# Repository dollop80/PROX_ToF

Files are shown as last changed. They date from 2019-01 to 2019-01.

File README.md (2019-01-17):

# Copter Obstacle Avoidance for Ardupilot - PROX_ToF
The obstacle avoidance module is based on ToF (Time of Flight) distance sensors VL53L1. The module is rather small and lightweight so it can fit even 140mm frame



You can read about obstacle avoidance in Ardupilot [here](http://ardupilot.org/dev/docs/code-overview-object-avoidance.html)

## What do you need:
- PROX_ToF PCB and parts
- Ardupilot compatible flight controller (Pixhawk, Omnibus, Pixracer, etc)
- Optical flow sensor (FlowDeck or Cheerson CX-OF)
- Any AVR ISP programmer to flash bootloader
- Your favorite quad, tri, hexa, octo :)

## Preparing Hardware:
- Assemble your [PROX_ToF module](https://github.com/dollop80/PROX_ToF/tree/master/HW) and flash a bootloader using AVR ISP and Arduino IDE (See Preparing Software)
- Print a [case](https://github.com/dollop80/PROX_ToF/tree/master/3D)
- Prepare all the nessesary connectors and wires
- Put your optical flow sensor on the bottom of the case
- Connect the module to flight controller
[Connection diagram](http://ixbt.photo/photo/259904/60047adsphykfW1/1266301w.jpg)

## Preparing Software:
- Flash a bootloader using AVR ISP and Arduino IDE if you haven't done it yet
- Compile and Upload the VL53L1_MULTI_MAVLINK.ino sketch. If you have any errors regarding libraries, install the libraries to your Arduino IDE from this repository
- Follow the instruction how to [build Ardupilot firmware](http://ardupilot.org/dev/docs/building-the-code.html);
- After cloning the repository and succesfull building the ArduCopter firmware, change your board's **hwdef.dat** file (in my case it is located \libraries\AP_HAL_ChibiOS\hwdef\omnibusf4pro\hwdef.dat bacause I used Omnibus F4 RPO FC):
1. Find the CS pins definitions (line #67) and add a line
```
PD2 FLOW_CS CS
```
2. Find the SPI Device table and comment the OSD SPI (SPI3 DEVID4). Instead the OSD add the optical flow device:
```
SPIDEV pixartflow SPI3 DEVID4 FLOW_CS MODE3 2MHZ 2MHZ
env DEFINES HAL_HAVE_PIXARTFLOW_SPI
```
3. Comment out the OSD defines (line #135)
```
#define OSD_ENABLED ENABLED
#define HAL_OSD_TYPE_DEFAULT 1
```
- Configure and build the copter firmware. Flash your FC
- Using MissionPlanner adjust the following parameters:
```
EK2_ALT_SOURCE = 1
EK2_GPS_TYPE = 3
FLOW_ENABLE = 1
RNGFND_TYPE = 16
RNGFND_MAX_CM = 140
```
## Checking that everything works
- Connect to your FC using MissionPlanner and press Ctrl+F button
- Push the Proximity button
- Check that you see the Radar and it reacts to distance change
[](http://ardupilot.org/dev/_images/code-overview-object-avoidance4.png)
- Arm and takeoff in Altitude Hold mode, you'll notice that your drone will react on closing up objects trying to avoid any possible collision. Try Loiter.

## My thanks
Thanks to patrickpoirier51 work https://github.com/patrickpoirier51/POC it was a good start for MAVLINK DISTANCE MESSAGE generation

Thanks to [Vitaly Puzrin](http://forum.rcdesign.ru/member.php?u=349) for general thoughts and instructions of writing README

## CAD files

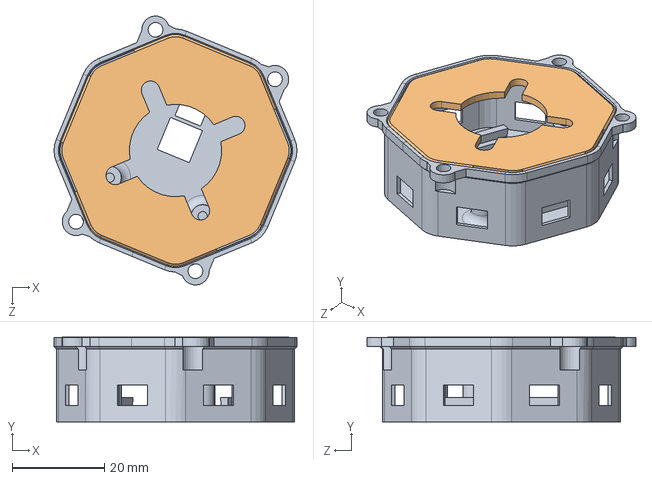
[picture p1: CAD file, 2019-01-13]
3D/Prox_ToF_OF.SLDASM
52.6 x 18.4 x 58.3 mm
Prox_ToF_OF
Prox_ToF_OF_Bot

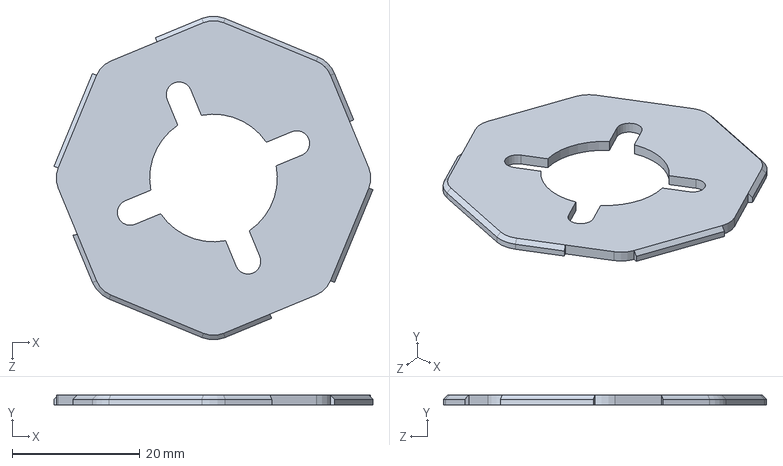
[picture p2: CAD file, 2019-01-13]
3D/Prox_ToF_OF_Bot.SLDPRT
50.0 x 1.60 x 50.6 mm

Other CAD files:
3D/Prox_ToF_OF.SLDDRW
3D/Prox_ToF_OF.SLDPRT
3D/Prox_ToF_OF.STL
3D/Prox_ToF_OF_Bot.STL

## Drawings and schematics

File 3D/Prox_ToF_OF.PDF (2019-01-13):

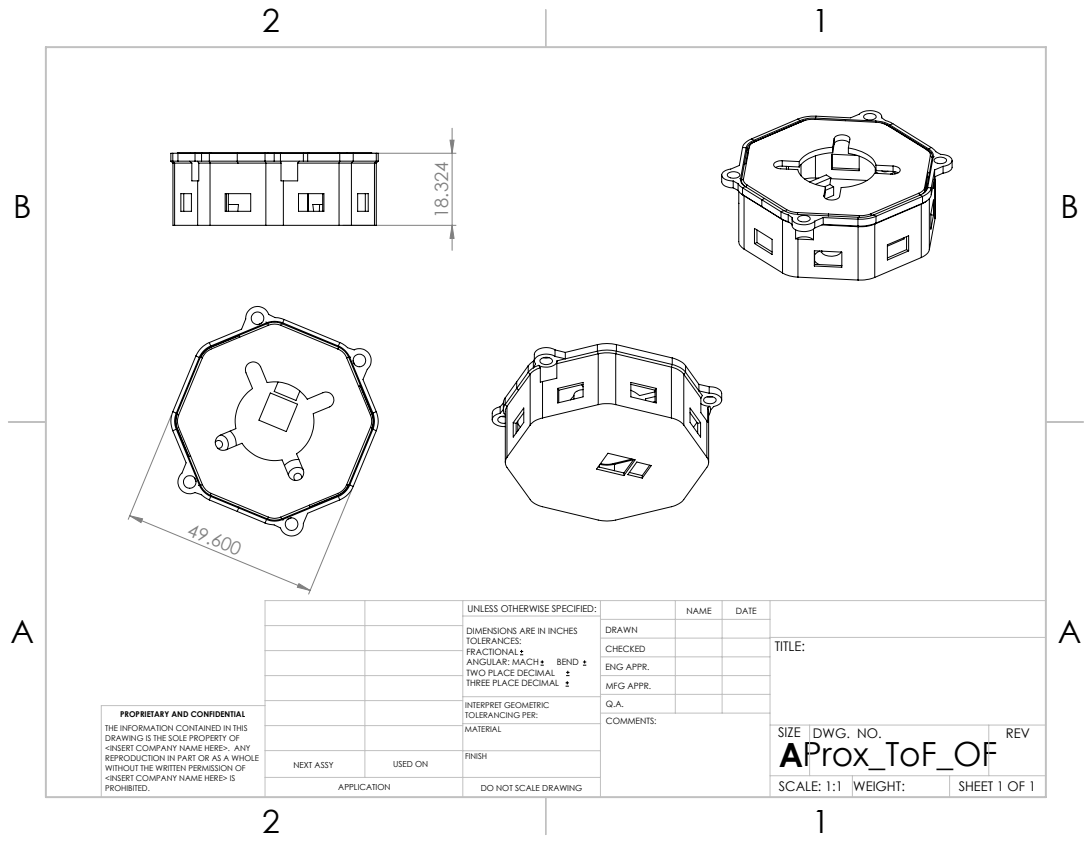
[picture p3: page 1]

UNLESS OTHERWISE SPECIFIED: | | NAME | DATE
DIMENSIONS ARE IN INCHES TOLERANCES: FRACTIONAL ANGULAR: MACH BEND TWO PLACE DECIMAL THREE PLACE DECIMAL | DRAWN

CHECKED | | | TITLE:

ENG APPR.
MFG APPR.

INTERPRET GEOMETRIC TOLERANCING PER: | Q.A.
MATERIAL | | SIZE A Prox_ToF_OF | DWG. NO. | REV

PROPRIETARY AND CONFIDENTIAL
THE INFORMATION CONTAINED IN THIS
DRAWING IS THE SOLE PROPERTY OF
<INSERT COMPANY NAME HERE>. ANY
REPRODUCTION IN PART OR AS A WHOLE
WITHOUT THE WRITTEN PERMISSION OF
<INSERT COMPANY NAME HERE> IS
PROHIBITED.

NEXT ASSY | USED ON | FINISH

APPLICATION | DO NOT SCALE DRAWING | | SCALE: 1:1 | WEIGHT: | SHEET 1 OF 1

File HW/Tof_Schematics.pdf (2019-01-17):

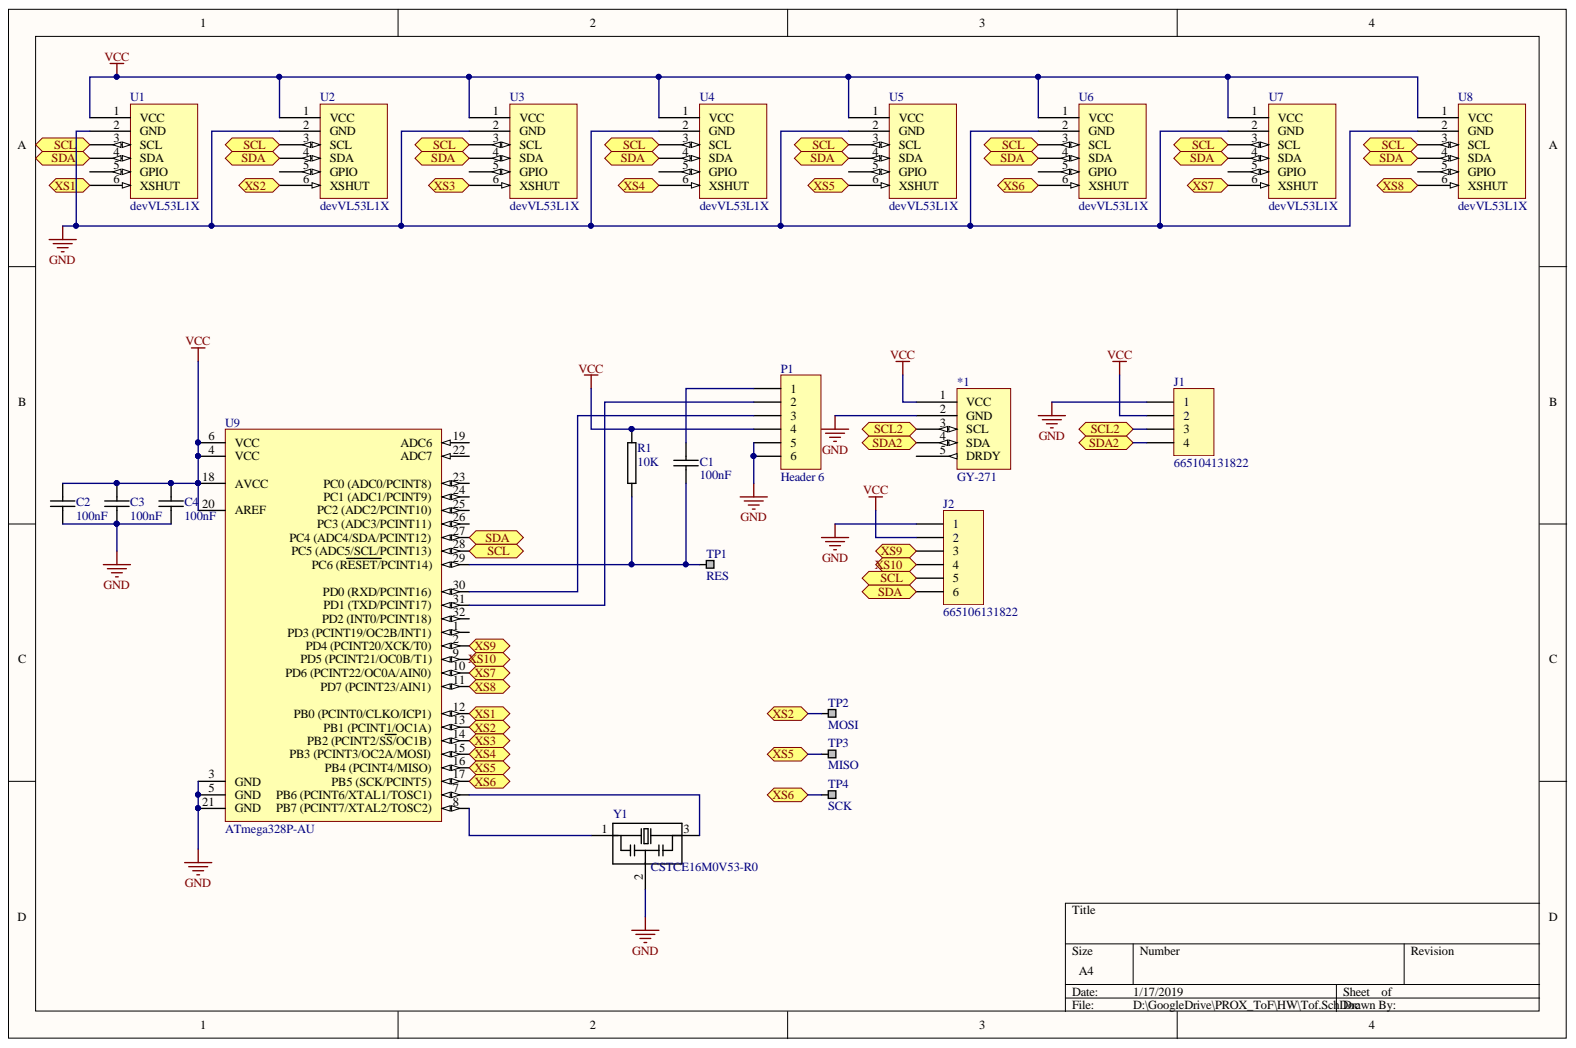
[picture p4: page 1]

Date: 1/17/2019 | Sheet of
File: D:\GoogleDrive\PROX_ToF\HW\Tof.SchDDocrawn By:

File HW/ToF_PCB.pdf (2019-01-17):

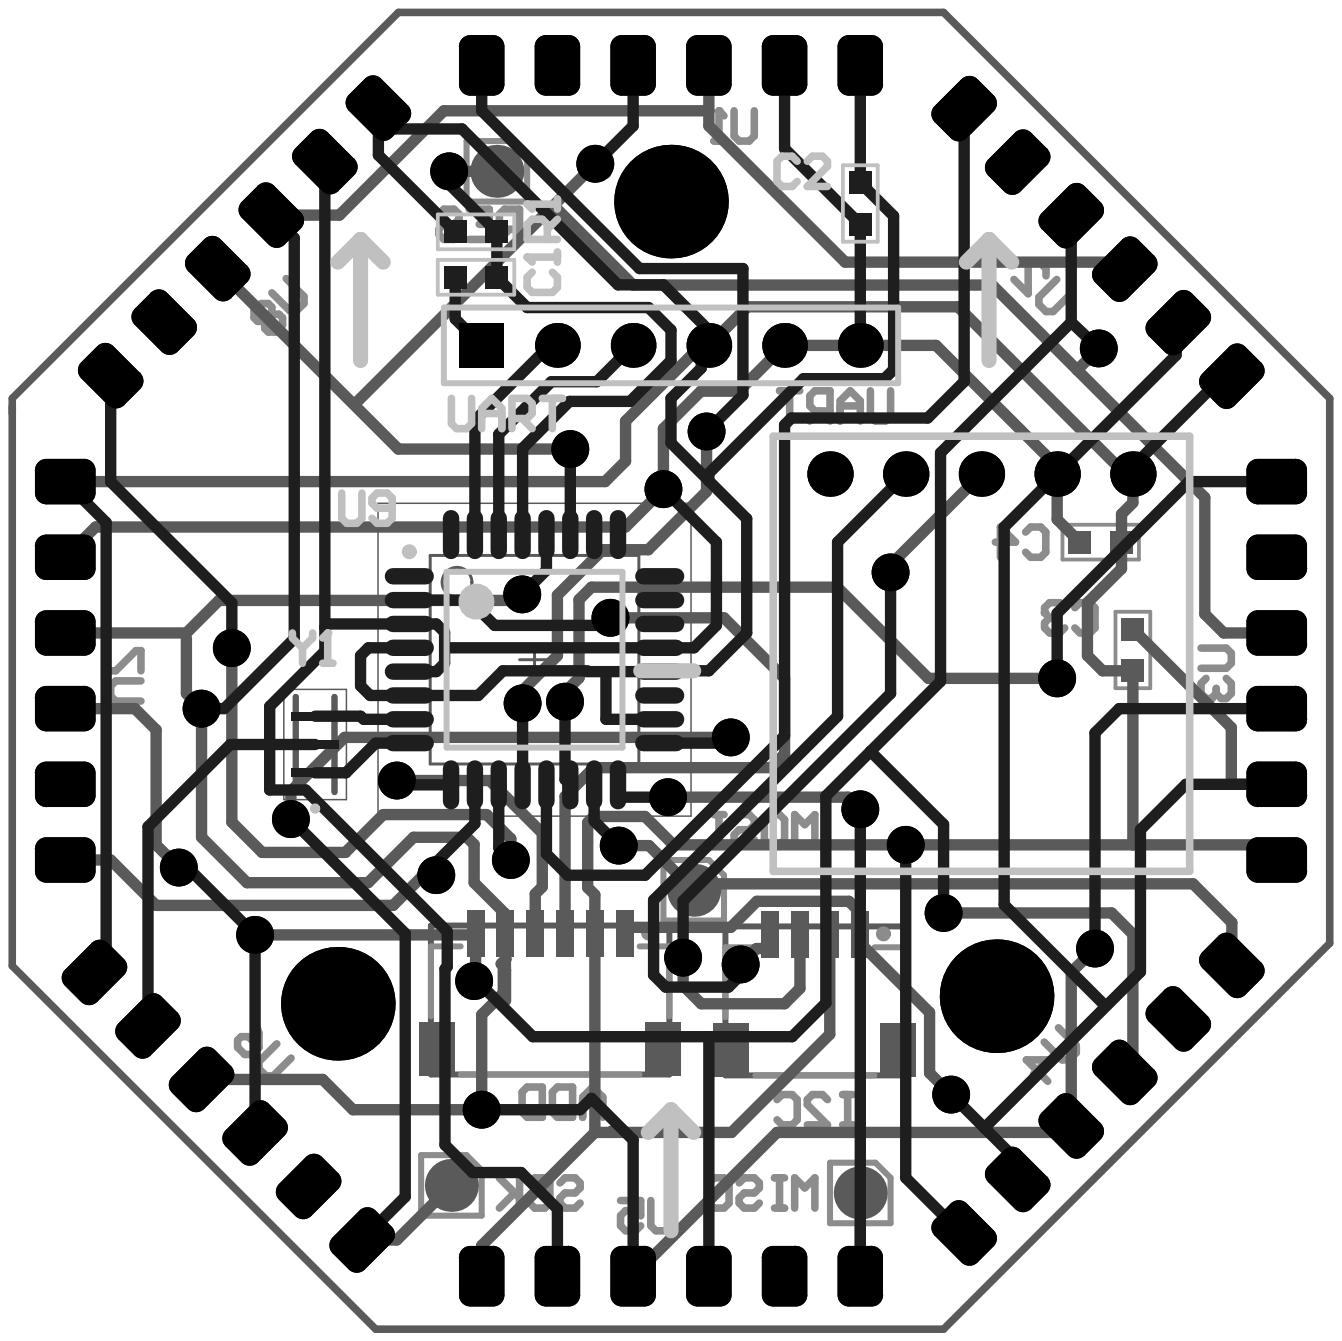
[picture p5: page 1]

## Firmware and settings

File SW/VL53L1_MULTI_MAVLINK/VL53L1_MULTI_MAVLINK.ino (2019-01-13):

#include "mavlink.h"        // Mavlink interface
#include "common/mavlink_msg_distance_sensor.h"

#include <Wire.h>
#include <VL53L1X.h>
const int MIN = 10;
const int MAX = 3000;

/*
Valid values are (even numbers only):
Pre: 12 to 18 (initialized to 14 by default)
Final: 8 to 14 (initialized to 10 by default)
*/
const int PreRng = 18;  
const int PostRng = 14;

const int Scale = 10;
#define bRate 115200


int XSHUT_pins[9] = {8, 9, 10, 11, 12, 13, 6, 7, 5};
//int orient[9] = {0, 1, 2, 3, 4, 5, 6, 7, 24};
int orient[9] = {0, 7, 6, 5, 4, 3, 2, 1, 24};


//ADDRESS_DEFAULT 0x52
uint8_t addr[9] = {90, 83, 84, 85, 86, 87, 88, 89, 91};

float SensorSmooth[9];
float SensorFilter[9];

VL53L1X sensor[9];

void setup()
{ /*WARNING*/
  //Shutdown pins of VL53L0X ACTIVE-LOW-ONLY NO TOLERANT TO 5V will fry them
  for (int i=0; i<sizeof(XSHUT_pins);i++)
  {
    pinMode(XSHUT_pins[i], OUTPUT);
    }

  Serial.begin(115200);
  
  Wire.begin();
  Wire.setClock(400000); // use 400 kHz I2C
  
  for(int i = 7; i >= 0; i--)
  {

    pinMode(XSHUT_pins[i], INPUT);
    delay(10);
    
    sensor[i].setTimeout(500);
    if(!sensor[i].init())
      Serial.println("Failed to detect and initialize sensor!");  
    sensor[i].setAddress(addr[i]);

  }

  for(int i = 7; i >= 0; i--)
  {
    // Use long distance mode and allow up to 50000 us (50 ms) for a measurement.
    // You can change these settings to adjust the performance of the sensor, but
    // the minimum timing budget is 20 ms for short distance mode and 33 ms for
    // medium and long distance modes. See the VL53L1X datasheet for more
    // information on range and timing limits.
    sensor[i].setDistanceMode(VL53L1X::Long);
    sensor[i].setMeasurementTimingBudget(35000);
  
    // Start continuous readings at a rate of one measurement every 50 ms (the
    // inter-measurement period). This period should be at least as long as the
    // timing budget.
    sensor[i].startContinuous(33);
  }
}

void loop()
{

/*
for(int i = 6; i>=2; i--)
{
   SensorSmooth[i] = sensor[i].readRangeContinuousMillimeters();
   SensorFilter[i] = constrain(SensorSmooth[i], MIN , MAX);
   Serial.print(SensorFilter[i]); 
   Serial.print(",");
}

  Serial.println();
  delay (0.1);
*/
  for(int i = 7; i >= 0; i--){
    command_distance(&sensor[i], orient[i]);
  }
}



void command_heartbeat() {

  //< ID 1 for this system
  int sysid = 100;                   
  //< The component sending the message.
  int compid = MAV_COMP_ID_PATHPLANNER;    
  
  // Define the system type, in this case ground control station
  uint8_t system_type =MAV_TYPE_GCS;
  uint8_t autopilot_type = MAV_AUTOPILOT_INVALID;
  
  uint8_t system_mode = 0; 
  uint32_t custom_mode = 0;                
  uint8_t system_state = 0;
  
  // Initialize the required buffers
  mavlink_message_t msg;
  uint8_t buf[MAVLINK_MAX_PACKET_LEN];
  
  // Pack the message
  mavlink_msg_heartbeat_pack(sysid,compid, &msg, system_type, autopilot_type, system_mode, custom_mode, system_state);
  
  // Copy the message to the send buffer
  uint16_t len = mavlink_msg_to_send_buffer(buf, &msg);
  
  // Send the message 
  //delay(1);
  Serial.write(buf, len);
}


void command_distance(VL53L1X *sensor, int orient) {

// READ THE DISTANCE SENSOR
  float SensorSmooth = sensor->readRangeContinuousMillimeters();
  SensorSmooth = constrain(SensorSmooth, MIN , MAX);
  float dist = SensorSmooth / Scale;

  //MAVLINK DISTANCE MESSAGE
  int sysid = 1;                   
  //< The component sending the message.
  int compid = 158;

  uint32_t time_boot_ms = 0; /*< Time since system boot*/
  uint16_t min_distance = 1; /*< Minimum distance the sensor can measure in centimeters*/
  uint16_t max_distance = 300; /*< Maximum distance the sensor can measure in centimeters*/
  uint16_t current_distance = dist; /*< Current distance reading*/
  uint8_t type = 0; /*< Type from MAV_DISTANCE_SENSOR enum.*/
  uint8_t id = orient; /*< Onboard ID of the sensor*/
  uint8_t orientation = orient; /*(0=forward, each increment is 45degrees more in clockwise direction), 24 (upwards) or 25 (downwards)*/
// Consumed within ArduPilot by the proximity class

  uint8_t covariance = 0; /*< Measurement covariance in centimeters, 0 for unknown / invalid readings*/


  // Initialize the required buffers
  mavlink_message_t msg;
  uint8_t buf[MAVLINK_MAX_PACKET_LEN];

  // Pack the message
  mavlink_msg_distance_sensor_pack(sysid,compid,&msg,time_boot_ms,min_distance,max_distance,current_distance,type,id,orientation,covariance);

  // Copy the message to the send buffer
  uint16_t len = mavlink_msg_to_send_buffer(buf, &msg);

  Serial.write(buf, len);
}
